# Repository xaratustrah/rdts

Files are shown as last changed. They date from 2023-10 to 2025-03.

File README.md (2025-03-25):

# RDTS - Raspberry Pi Distributed Trigger System

RDTS

RDTS is a scalable hardware triggering system for data acquisition devices such as data loggers, oscilloscopes or spectrum analysers. The output can be used in order to trigger several devices.

The code also provides a delayed trigger exactly half of the assigned value. This feature allows for alternate triggering of two devices that are monitoring the same signal.

The code can be operated in stand alone mode for manual or time based trigger. In the client / server mode, many devices can be triggered at once.

#### Schematics
The schematics has been creating using [KiCAD](https://www.kicad.org/). The schematics file is included in the project. A PDF version of the schematics (connection plan) can be found [here](https://github.com/xaratustrah/rdts/blob/main/rsrc/rdts.kicad_sch.pdf). Needed parts are listed also in an spread sheet document [here](https://github.com/xaratustrah/rdts/blob/main/rsrc/rdts_part_list.ods).

#### Installation
After cloning the code of the repository, go inside that directory and type:

```
pip install -r requirements.txt
pip3 install .
```

or uninstall

```
pip3 uninstall rdts
```

#### Stand alone trigger: `rdts_cliserv`

This is a stand alone trigger machine that triggers every XXX seconds and writes the trigger times in a log file, where XXX is a value that you enter int the command line. Trigger every 2 seconds and record the times in a log file:

```
rdts_timer --time 2 --logfile test.txt
```

You can interrupt the trigger by pressing `ctrl-C`. By doing so, one last trigger will be issued. So this can be used for single arbitrary triggers, like you set the trigger time to something large, but then break at your wish.

#### Client-Server based remote trigger: `rdtscli`

This one is a client/server code that allows for a distributed trigger box system. The server is run on the the computer. The client on one or many trigger boxes. It accepts only IP addresses not names. Please also provide port numbers. The IP address is *always* the one of the computer, not of the RDTS box! For example:

On the computer you run the server:

```
rdts_cliserv --server --host 192.168.1.3 --port 1434
```

here `host` is the IP address of the computer, who is acting as a server, not the one of the Trigger box!

similarly on the RDTS side, you run the client:

```
rdts_cliserv --client --host 192.168.1.3 --port 1434
```

here the same information as above, that is, again here the IP address and port numnber of the server computer is used not of the RDTS trigger box.

## Licensing

Please see the file [LICENSE.md](./LICENSE.md) for further information about how the content is licensed.

## Acknowledgements

Many thanks to Davide Racano for providing help with the mechanical preparation of the enclosure.

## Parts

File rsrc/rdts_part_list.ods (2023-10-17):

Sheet: Part Numbers
Part list for RDTS
https://github.com/xaratustrah/rdts
How many | Part | Brand | Distributor | Distro Order # | Description
1 | Raspberry Pi 3B+ | Raspberry Pi 3B+ | - | - | Raspberry Pi 3B+
1 | - | - | - | - | Resistor 270R
4 | - | - | - | - | Resistor 10k
2 | TC-10101488 | TRU Components | Conrad | 2525372 | TRU COMPONENTS TC-10101488 BNC-Steckverbinder Buchse, Einbau vertikal 50 Ω
1 | SMQ1089 | Signal Construct | Conrad | 185949 | Signal Construct SMQ1089 SMQ1089 LED-Fassung Metall Passend für (LEDs) LED 5 mm Schraubbefestigung
1 | 1229322 | TRU Components | Conrad | 1229322 | USB-Doppeleinbaubuchse 2.0 Buchse, Einbau USB-06-BK 2 x USB-Buchse Typ A auf 2 x USB-Stecker Typ A mit 60 cm Kabel 12293
1 | 1408770 | TRU Components | Conrad | 1408770 | TRU COMPONENTS RJ45-01 RJ45-Einbaubuchse 1408770 Buchse, Einbau, Stecker, gerade Polzahl 8P8C Silber
1 | TXL 025-05S | Traco Power | Conrad | 511024 | TracoPower TXL 025-05S AC/DC-Einbaunetzteil 5 A 25 W 5 V/DC
1 | TC-02747-40-1-00-2 | TRU Components | Conrad | 1560769 | TRU COMPONENTS TC-02747-40-1-00-2 Stiftleiste Rastermaß: 2.54 mm Polzahl Gesamt: 40 Anzahl Reihen: 2
1 | MIKRO-PIEPSER |  | Conrad | 751553 | MIKRO-PIEPSER Signalgeber Geräusch-Entwicklung: 85 dB Spannung: 5 V Dauerton
2 | BS170 | ON Semi | Conrad | 158950 | ON Semiconductor BS170 MOSFET 1 N-Kanal 350 mW TO-92
1 | L-53 LGD | Kingbright | Conrad | 146030 | Kingbright L 53 LGD LED bedrahtet Grün Rund 5 mm 2 mcd 60 ° 2 mA 2.2 V
1 | TC-8990608 | TRU Components | Conrad | 2247652 | TRU COMPONENTS Strom-Kabel Raspberry Pi [1x USB 2.0 Stecker Micro-B - 1x offene Kabelenden] 1.00 m Schwarz
1 | 4301.1407 | Schurter | Distrelec | 169-62-956 | Fuse drawer for DD11.0114.1111
1 | DD11.0114.1111 | Schurter | Distrelec | 169-63-555 | Inlet, C14, 250V, Schurter, 1-pole fuse holder, illuminated green
1 | RC320-07 | Schurter | Distrelec | 303-02-323 | Rear cover, protection
1 | - | RS Pro | RS | 188-1318 | RS PRO 19 Zoll Rack Gehäuse 2U Schwarz, 425 mm x 425mm x 84 mm
6 | - | RS Pro | RS | 897-1332 | RS PRO Printklemme / Stecker, THT, 2-polig / 1-reihig, Raster 3.5mm
2 | AWP 40-7240-T | Assmann | RS | 674-1110 | ASSMANN WSW AWP IDC-Steckverbinder Buchse, gewinkelt, 40-polig / 2-reihig, Raster 2.54mm
1 | - | RS Pro | RS | 289-9975 | RS PRO Flachbandkabel , 40-adrig, Raster 1.27mm Nicht abgeschlossen 50,8 mm

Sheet: Relay Board Connector
Name | Pin # | Function
5V | 1 | PWR
5V | 2 | PWR
REL1 | 3 | BLUE
REL2 | 4 | BLUE
REL3 | 5 | BLUE
REL4 | 6 | BLUE
REL5 | 7 | BLUE
REL6 | 8 | BRK0
REL7 | 9 | DRV-SEL
REL8 | 10 | DRV-SEL
REL9 | 11 | BRK1
REL10 | 12 | BRK2
REL11 | 13 | BRK3
REL12 | 14 | GREEN
REL13 | 15 | GREEN
REL14 | 16 | GREEN
REL15 | 17 | GREEN
REL16 | 18 | GREEN
GND | 19 | PWR
GND | 20 | PWR

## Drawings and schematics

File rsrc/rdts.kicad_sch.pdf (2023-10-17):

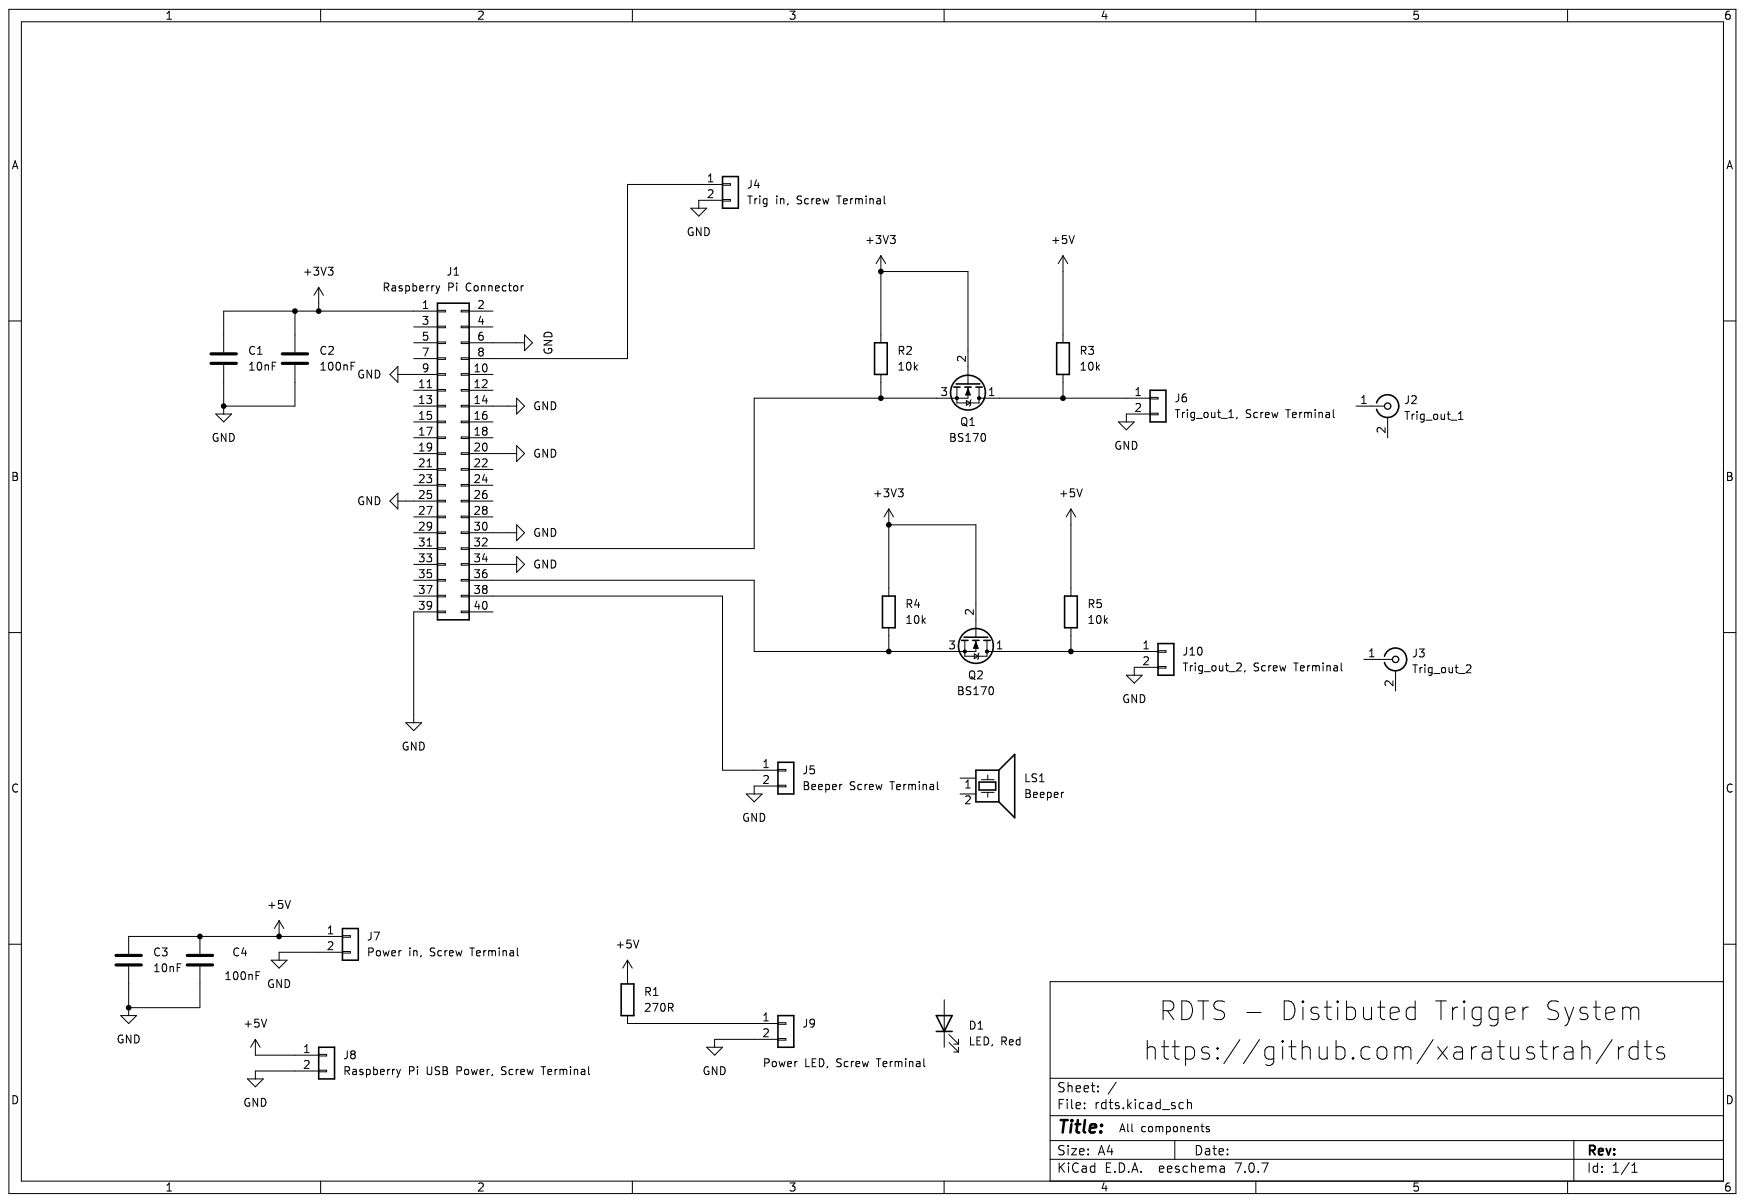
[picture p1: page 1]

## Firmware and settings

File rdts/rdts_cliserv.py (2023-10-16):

#!/usr/bin/env python
"""
A client/server code for Raspberry PI as a distributed trigger box system

Xaratustrah
2016
2023

"""

import datetime, time
import argparse
import zmq
import os

from .version import __version__

if os.name == 'posix' and os.uname().machine == 'armv7l':
    try:
        import RPi.GPIO as gpio
    except RuntimeError:
        print("""Error importing RPi.GPIO!  This is probably because you need superuser privileges.
                You can achieve this by using 'sudo' to run your script""")

# duration times in seconds
TRIGGER_DURATION = 0.1
BEEP_DURATION = 0.2

# Assing GPIO pin numbers

# Output pins
TRIG_IN = 8

# Input pins
BEEP = 38
TRIG_OUT = 32


def gpio_setup():
    # turn off warnings
    gpio.setwarnings(False)
    # we need board numbering system
    gpio.setmode(gpio.BOARD)
    gpio.setup(TRIG_IN, gpio.IN)

    gpio.setup(TRIG_OUT, gpio.OUT)
    gpio.output(TRIG_OUT, gpio.LOW)
    gpio.setup(BEEP, gpio.OUT)
    gpio.output(BEEP, gpio.LOW)


def do_trigger():
    gpio.output(TRIG_OUT, gpio.HIGH)
    time.sleep(TRIGGER_DURATION)
    gpio.output(TRIG_OUT, gpio.LOW)

    gpio.output(BEEP, gpio.HIGH)
    time.sleep(BEEP_DURATION)
    gpio.output(BEEP, gpio.LOW)


def start_server(host, port):
    context = zmq.Context()
    sock = context.socket(zmq.PUB)

    topic = '10002'  # just a number for identification
    print("Server started on tcp://{}:{}".format(host, port))
    sock.bind("tcp://{}:{}".format(host, port))
    while True:
        try:
            input('\nPress enter to trigger. ctrl-c to abort.')
            current_time = datetime.datetime.now().strftime('%Y-%m-%d@%H:%M:%S.%f')
            sock.send_string("{} {}".format(topic, current_time))
            print("Last triggered at {}.".format(current_time))

        except(EOFError, KeyboardInterrupt):
            print('\nUser input cancelled. Aborting...')
            break


def start_client(host, port):
    # setup GPIO
    gpio_setup()
    context = zmq.Context()
    print('Client started. Listening to tcp://{}:{}. ctrl-c to abort.\n'.format(host, port))
    try:
        sock = context.socket(zmq.SUB)
        sock.connect("tcp://{}:{}".format(host, port))
        topic_filter = '10002'
        sock.setsockopt_string(zmq.SUBSCRIBE, topic_filter)

        while True:
            string = sock.recv().decode("utf-8")
            current_time = datetime.datetime.now().strftime('%Y-%m-%d@%H:%M:%S.%f')
            do_trigger()
            print("Triggered by server. Server time: {}, client time: {}".format(string, current_time))


    except(ConnectionRefusedError):
        print('Server not running. Aborting...')

    except(EOFError, KeyboardInterrupt):
        print('\nUser input cancelled. Aborting...')


def main():
    parser = argparse.ArgumentParser(prog='rdts_cliserv')
    parser.add_argument('--host', nargs=1, type=str, help='Host address', default='127.0.0.1')
    parser.add_argument('--port', nargs=1, type=int, help='Port number', default=1234)
    parser.add_argument('--version', action='version', version=__version__)
    group = parser.add_mutually_exclusive_group()
    group.add_argument('--client', action='store_true', help='Start client')
    group.add_argument('--server', action='store_true', help='Start server')
    parser.set_defaults(server=False)
    parser.set_defaults(client=False)

    args = parser.parse_args()
    # check the first switches

    if isinstance(args.host, list):
        host = args.host[0]
    else:
        host = args.host

    if isinstance(args.port, list):
        port = args.port[0]
    else:
        port = args.port

    if args.server:

        start_server(host, port)

    elif args.host:
        start_client(host, port)

    else:
        parser.print_help()


# ----------------------------

if __name__ == '__main__':
    main()

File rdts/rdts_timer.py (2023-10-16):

#!/usr/bin/env python
"""
A trigger with a timer. Triggers every XXX seconds and records the times in a log file.

xaratustrah

2021
2023

"""

import datetime
import time
import argparse
import os

from .version import __version__

if os.name == 'posix' and os.uname().machine == 'armv7l':
    try:
        import RPi.GPIO as gpio
    except RuntimeError:
        print("""Error importing RPi.GPIO!  This is probably because you need superuser privileges.
                You can achieve this by using 'sudo' to run your script""")


# duration times in seconds
TRIGGER_DURATION = 0.1
BEEP_DURATION = 0.2

# Assing GPIO pin numbers

# Output pins
TRIG_IN = 8

# Input pins
BEEP = 38
TRIG_OUT1 = 32
TRIG_OUT2 = 36


def gpio_setup():
    # turn off warnings
    gpio.setwarnings(False)
    # we need board numbering system
    gpio.setmode(gpio.BOARD)
    gpio.setup(TRIG_IN, gpio.IN)

    gpio.setup(TRIG_OUT1, gpio.OUT)
    gpio.output(TRIG_OUT1, gpio.LOW)

    gpio.setup(TRIG_OUT2, gpio.OUT)
    gpio.output(TRIG_OUT2, gpio.LOW)

    gpio.setup(BEEP, gpio.OUT)
    gpio.output(BEEP, gpio.LOW)


def do_trigger_first():
    gpio.output(TRIG_OUT1, gpio.HIGH)
    time.sleep(TRIGGER_DURATION)
    gpio.output(TRIG_OUT1, gpio.LOW)

    gpio.output(BEEP, gpio.HIGH)
    time.sleep(BEEP_DURATION)
    gpio.output(BEEP, gpio.LOW)

def do_trigger_second():
    gpio.output(TRIG_OUT2, gpio.HIGH)
    time.sleep(TRIGGER_DURATION)
    gpio.output(TRIG_OUT2, gpio.LOW)

def start_trigger(trig_time, logfile):
    gpio_setup()
    print('Triggering every {} seconds. Otherwise press ctrl-c to trigger once and abort.'.format(trig_time))
    f = open(logfile, "a")
    try:
        # we wait first one whole trig_time
        time.sleep(trig_time)
        while True:
            # first trigger
            current_time = datetime.datetime.now().strftime('%Y-%m-%d@%H:%M:%S.%f')
            print('Triggering at: {}'.format(current_time))
            do_trigger_first()
            time.sleep(trig_time / 2)
            
            # second trigger offset by half of the period
            do_trigger_second()
            time.sleep(trig_time / 2)
            f.write(current_time + '\n')

    except(KeyboardInterrupt, EOFError):
        print('\n\nUser cancelled. Please wait for the last trigger...')
        current_time = datetime.datetime.now().strftime('%Y-%m-%d@%H:%M:%S.%f')
        print('Last trigger issued at: {}'.format(current_time))

        do_trigger_first()
        time.sleep(trig_time / 2)
        do_trigger_second()
        time.sleep(trig_time / 2)
        
        f.write(current_time + '\n')
        print('\nDone.')
        f.close()


def main():
    parser = argparse.ArgumentParser(prog='rdts_timer')
    parser.add_argument('--logfile', nargs=1, type=str,
                        help='name of the logfile', default='trigtimer.log')
    parser.add_argument('--time', nargs=1, type=int,
                        help='Trigger time in seconds', default=5)
    parser.add_argument('--version', action='version', version=__version__)

    args = parser.parse_args()
    # check the first switches
    trigtime = int(args.time[0])
    if isinstance(args.logfile, list):
        logfile = args.logfile[0]
    else:
        logfile = args.logfile

    start_trigger(trigtime, logfile)

# ----------------------------


if __name__ == '__main__':
    main()
